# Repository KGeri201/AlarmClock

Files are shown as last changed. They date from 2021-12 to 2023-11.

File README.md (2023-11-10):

alarm clock

# Alarm Clock
An Open-Source, easy to build alarm clock.

## Description
To make sure, that I can be in time I wanted to buy a new alarm clock to have beside my smartphone.  
I wanted one which is reliable, not depending on wall power and I can set, manage multiple alarms easily.  
I searced through some sites, but I could not find any, which I liked.  
So I designed my own.  
I wanted to mimik the clock of a general smartphone and set alarms easily through a touchscreen.  
Because I use an ESP32 I also hope to be able to display some notifications through bluetooth and use other features of it in the future.   

## Hardware
### PCB
It is a nearly one sided PCB.   
Unfortunatelly I had to make some GND-connections to the second site to make the design some sort of clean.  

#### Partlist  
|Amount | Value | Designation
|-|-|-
| 1 | ESP32-WROOM-32 (ESP32) | ESP32 
| 1 | ER-TFTM032-3 | LCD 
| 1 | LD1117AS33TR (Voltage-Regulator) | IC1 
| 1 | SUMMER EPM 121 (buzzer) | SG1 
| 5 | 0,1µF | C1, C2, C4, C5, C6 
| 2 | 10µF | C3, C7 
| 4 | 10k | R1, R2, R3, R9 
| 1 | BC817 (NPN Transistor) | T1 
| 1 | Button | BTN 
| 3 | AAA Batteryholder | BT1, BT2, BT3  

As an optional accesory you can get a BME280 sensor module and connect it to the pinheader marked for it on the board.

### Case
It is an easy to print case.  
Probaly will make a new, improved version in the future.

## Pinout
|GPIO | Screen
|-|-
| 12 | MISO
| 13 | MOSI
| 14 | SCLK
| 15 | CS
| 2 | DC
| nc | RST
| 16 | T_SCL
| 27 | T_SDA

|GPIO | BME280
|-|-
|33|-
|25|-

|GPIO | Other
|-|-
|32| Button
|26| Speaker
|35| voltage divider

## Software
**W**ork **i**n **P**rogress

## Credits
[KGeri201](https://github.com/KGeri201)

Special thanks to [HimbeersaftLP](https://github.com/HimbeersaftLP) for the help.

## License
[Apache License 2.0](LICENSE)

## Project status
In development.

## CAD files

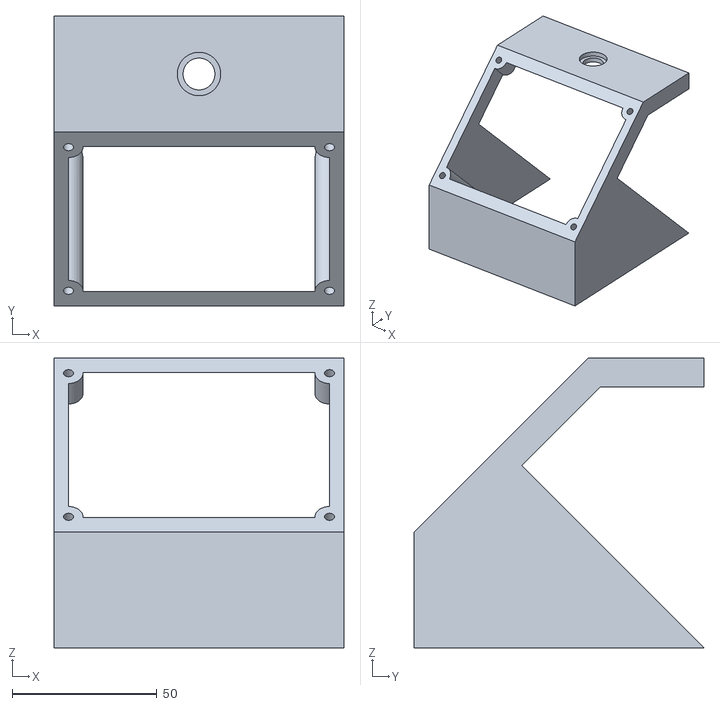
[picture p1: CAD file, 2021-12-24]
AlarmClock.stl
100.0 x 100.0 x 100.0

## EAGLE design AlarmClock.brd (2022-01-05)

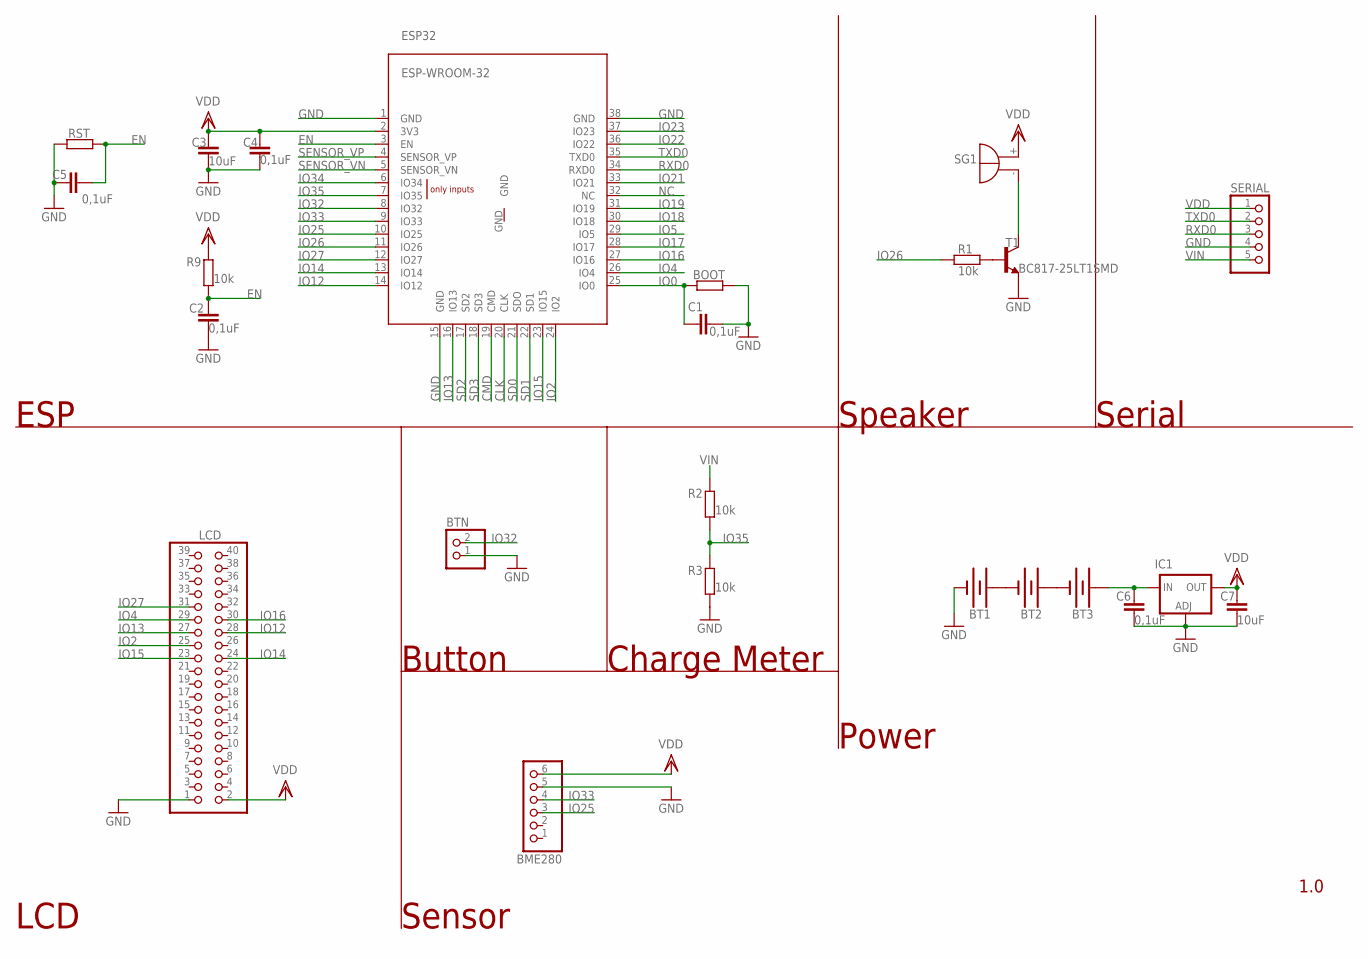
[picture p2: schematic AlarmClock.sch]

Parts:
BME280: PINHD-1X6; 1X06
BOOT: R-EU_R1206; R1206
BT1, BT2, BT3: HALTER1XUM4-LF
BTN: PINHD-1X2_2.54; 1X02
C1, C2, C4, C5, C6: 0,1uF; C1206
C3, C7: 10uF; C1206
ESP32: ESP-WROOM-32
IC1: LD1117AS33TR; SOT223
LCD: PINHD-2X20; 2X20
R1, R2, R3, R9: 10k; R1206
RST: R-EU_R1206; R1206
SERIAL: PINHD-1X5_2.54-SMD-90°; 1X05SMD/90
SG1: F/QMB
T1: BC817-25LT1SMD; SOT23-BEC

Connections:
CLK: ESP32.20 (CLK)
CMD: ESP32.19 (CMD)
EN: C2.2, C5.2, ESP32.3 (EN), R9.1, RST.2
GND: BME280.5, BOOT.2, BT1.P$2 (-), BTN.1, C1.1, C2.1, C3.1, C4.1, C5.1, C6.1, C7.1, ESP32.1 (GND), ESP32.15 (GND), ESP32.38 (GND), IC1.1 (ADJ), LCD.1, R3.1, RST.1, SERIAL.4, T1.E
IO0: BOOT.1, C1.2, ESP32.25 (IO0)
IO2: ESP32.24 (IO2), LCD.25
IO4: ESP32.26 (IO4), LCD.29
IO5: ESP32.29 (IO5)
IO12: ESP32.14 (IO12), LCD.28
IO13: ESP32.16 (IO13), LCD.27
IO14: ESP32.13 (IO14), LCD.24
IO15: ESP32.23 (IO15), LCD.23
IO16: ESP32.27 (IO16), LCD.30
IO17: ESP32.28 (IO17)
IO18: ESP32.30 (IO18)
IO19: ESP32.31 (IO19)
IO21: ESP32.33 (IO21)
IO22: ESP32.36 (IO22)
IO23: ESP32.37 (IO23)
IO25: BME280.3, ESP32.10 (IO25)
IO26: ESP32.11 (IO26), R1.1
IO27: ESP32.12 (IO27), LCD.31
IO32: BTN.2, ESP32.8 (IO32)
IO33: BME280.4, ESP32.9 (IO33)
IO34: ESP32.6 (IO34)
IO35: ESP32.7 (IO35), R2.1, R3.2
unnamed: SG1.- (+), T1.C
unnamed: BT1.P$1 (+), BT2.P$2 (-)
unnamed: BT2.P$1 (+), BT3.P$2 (-)
unnamed: R1.2, T1.B
NC: ESP32.32 (NC)
RXD0: ESP32.34 (RXD0), SERIAL.3
SD0: ESP32.21 (SDO)
SD1: ESP32.22 (SD1)
SD2: ESP32.17 (SD2)
SD3: ESP32.18 (SD3)
SENSOR_VN: ESP32.5 (SENSOR_VN)
SENSOR_VP: ESP32.4 (SENSOR_VP)
TXD0: ESP32.35 (TXD0), SERIAL.2
VDD: BME280.6, C3.2, C4.2, C7.2, ESP32.2 (3V3), IC1.4 (OUT), LCD.2, R9.2, SERIAL.1, SG1.+ (-)
VIN: BT3.P$1 (+), C6.2, IC1.3 (IN), R2.2, SERIAL.5

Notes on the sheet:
Power
1.0
ESP
LCD
Sensor
Button
Serial
Speaker
Charge Meter

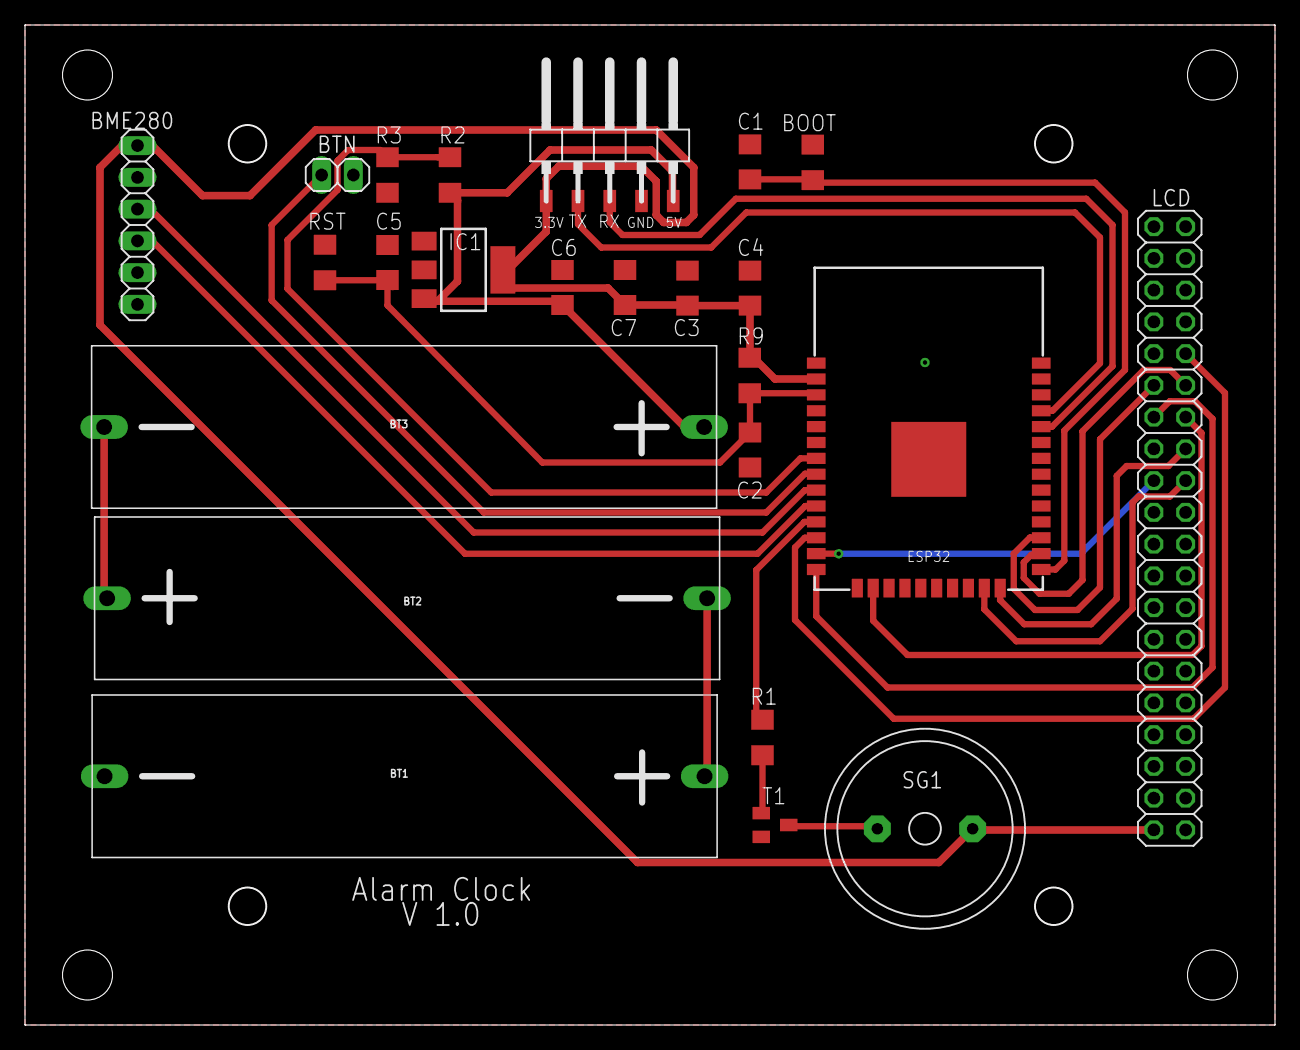
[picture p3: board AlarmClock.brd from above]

Board: 2 copper layers, 100.0 x 80.0 mm, 24 parts (0 on the bottom side), 24 nets.

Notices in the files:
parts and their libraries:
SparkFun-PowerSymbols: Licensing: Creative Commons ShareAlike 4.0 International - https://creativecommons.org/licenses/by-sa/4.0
